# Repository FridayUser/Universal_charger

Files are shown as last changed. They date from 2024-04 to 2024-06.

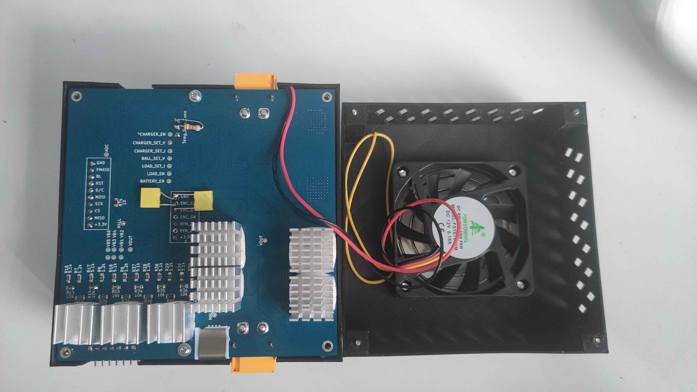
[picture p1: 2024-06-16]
Zdjęcia/IMG20240616181437.jpg

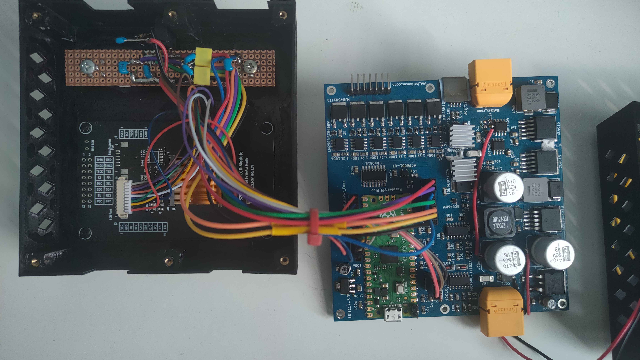
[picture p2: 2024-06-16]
Zdjęcia/IMG20240616181631.jpg

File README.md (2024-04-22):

View this project on [CADLAB.io](https://cadlab.io/project/28066). 

# Witam w projekcie ładowarki!

# Update plików
**Proszę o pisanie jasnego podsumowania i zwięzłych opisów** przy zatwierdzaniu plików. W szczególności plików innych niż programy. Pamietajcie, że po zatwierdzeniu należy też pliki przesłać. ewentualnie dodać jakieś nowe. Jeśli ktoś nie ogarnia gita to polecam wersję desktop.
## Tworzenie plików i folderów
Starajmy się twożyć jak najbardziej przejrzyście to repozytorium, żeby się poprostu nie zgubić w tym wszystkim

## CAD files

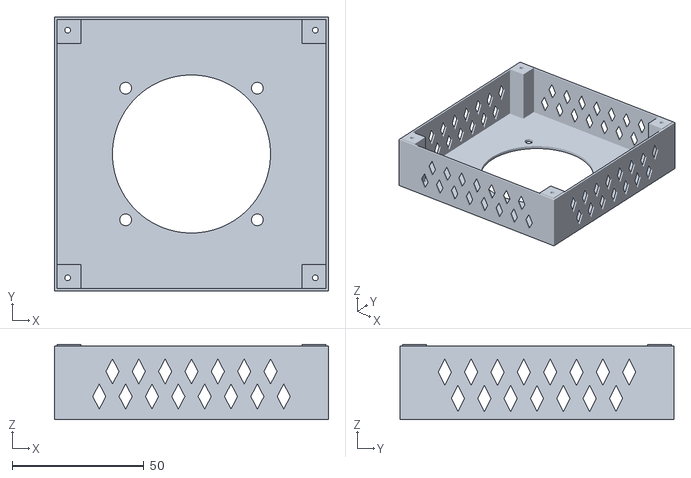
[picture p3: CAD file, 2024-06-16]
Obudowa/obudowa_d.stl
104.0 x 104.0 x 28.5

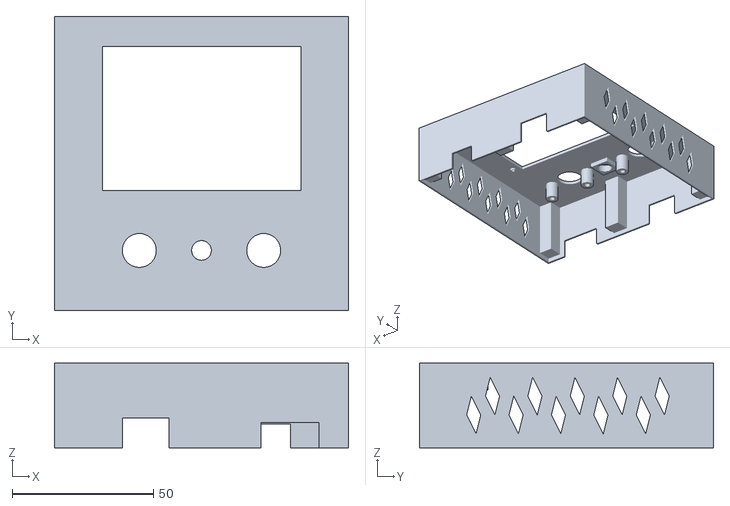
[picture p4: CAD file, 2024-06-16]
Obudowa/obudowa_t.stl
104.0 x 104.0 x 30.0

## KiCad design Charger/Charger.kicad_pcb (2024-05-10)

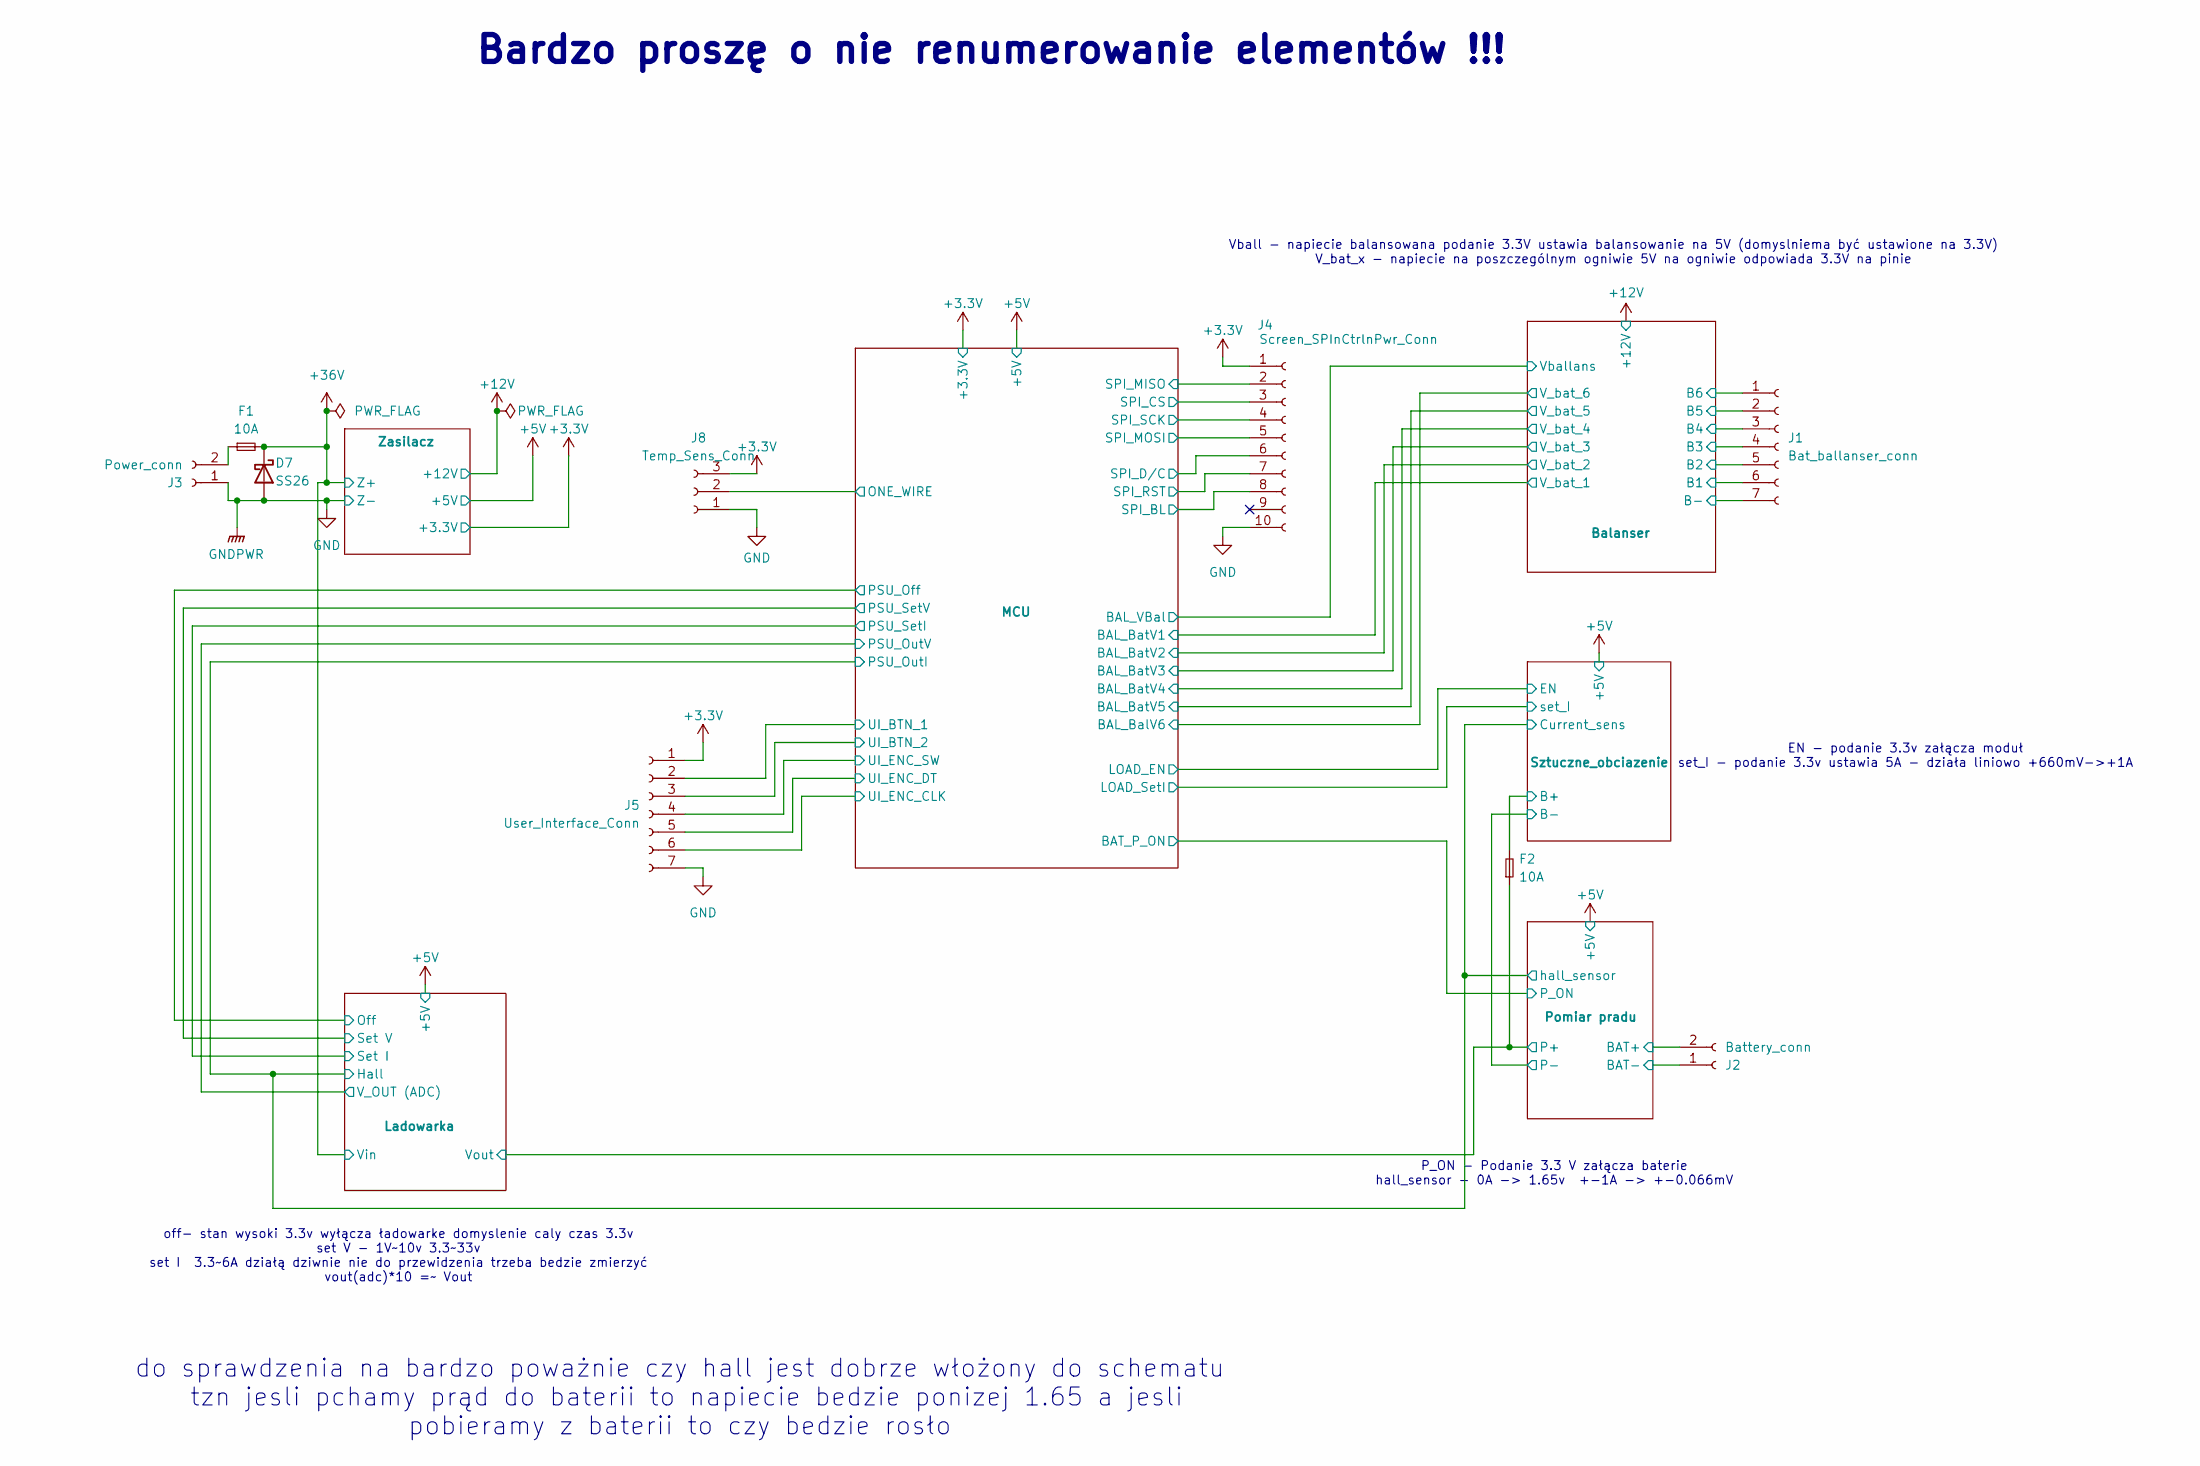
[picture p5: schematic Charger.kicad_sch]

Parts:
D7: SS26; D_SMA
F1, F2: 10A; Fuse_2010_5025Metric_Pad1.52x2.65mm_HandSolder
J1: Bat_ballanser_conn; PinHeader_1x07_P2.54mm_Horizontal
J2: Battery_conn; AMASS_XT60PW-M_1x02_P7.20mm_Horizontal
J3: Power_conn; AMASS_XT60PW-M_1x02_P7.20mm_Horizontal
J4: Screen_SPInCtrlnPwr_Conn; PinHeader_1x10_P2.54mm_Vertical
J5: User_Interface_Conn; PinHeader_1x07_P2.54mm_Vertical
J8: Temp_Sens_Conn; PinHeader_1x03_P2.54mm_Vertical

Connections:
+3.3V: J4.1, J5.1, J8.3; also elsewhere on the board
+36V: D7.1 (K), F1.2; also elsewhere on the board
/Balanser/B1: J1.6; also elsewhere on the board
/Balanser/B2: J1.5; also elsewhere on the board
/Balanser/B3: J1.4; also elsewhere on the board
/Balanser/B4: J1.3; also elsewhere on the board
/Balanser/B5: J1.2; also elsewhere on the board
/Balanser/B6: J1.1; also elsewhere on the board
/Ladowarka/Vout: F2.1; also elsewhere on the board
/Pomiar pradu/BAT+: J2.2; also elsewhere on the board
/Pomiar pradu/BAT-: J2.1; also elsewhere on the board
/Sztuczne_obciazenie/B+: F2.2; also elsewhere on the board
GND: D7.2 (A), J1.7, J3.1, J4.10, J5.7, J8.1; also elsewhere on the board
GPIO4: J8.2; also elsewhere on the board
GPIO11: J5.6; also elsewhere on the board
GPIO12: J5.5; also elsewhere on the board
GPIO13: J5.4; also elsewhere on the board
GPIO14: J5.3; also elsewhere on the board
GPIO15: J5.2; also elsewhere on the board
GPIO16: J4.2; also elsewhere on the board
GPIO17: J4.3; also elsewhere on the board
GPIO18: J4.4; also elsewhere on the board
GPIO19: J4.5; also elsewhere on the board
GPIO20: J4.6; also elsewhere on the board
GPIO21: J4.7; also elsewhere on the board
GPIO22: J4.8; also elsewhere on the board
unnamed: F1.1, J3.2

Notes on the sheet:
EN - podanie 3.3v załącza moduł set_I - podanie 3.3v ustawia 5A - działa liniowo +660mV->+1A
off- stan wysoki 3.3v wyłącza ładowarke domyslenie caly czas 3.3v set V - 1V~10v 3.3~33v set I 3.3~6A działą dziwnie nie do przewidzenia trzeba bedzie zmierzyć vout(adc)*10 =~ Vout
Bardzo proszę o nie renumerowanie elementów !!!
Vball - napiecie balansowana podanie 3.3V ustawia balansowanie na 5V (domyslniema być ustawione na 3.3V) V_bat_x - napiecie na poszczególnym ogniwie 5V na ogniwie odpowiada 3.3V na pinie
do sprawdzenia na bardzo poważnie czy hall jest dobrze włożony do schematu tzn jesli pchamy prąd do baterii to napiecie bedzie ponizej 1.65 a jesli pobieramy z baterii to czy bedzie rosło
P_ON - Podanie 3.3 V załącza baterie hall_sensor - 0A -> 1.65v +-1A -> +-0.066mV

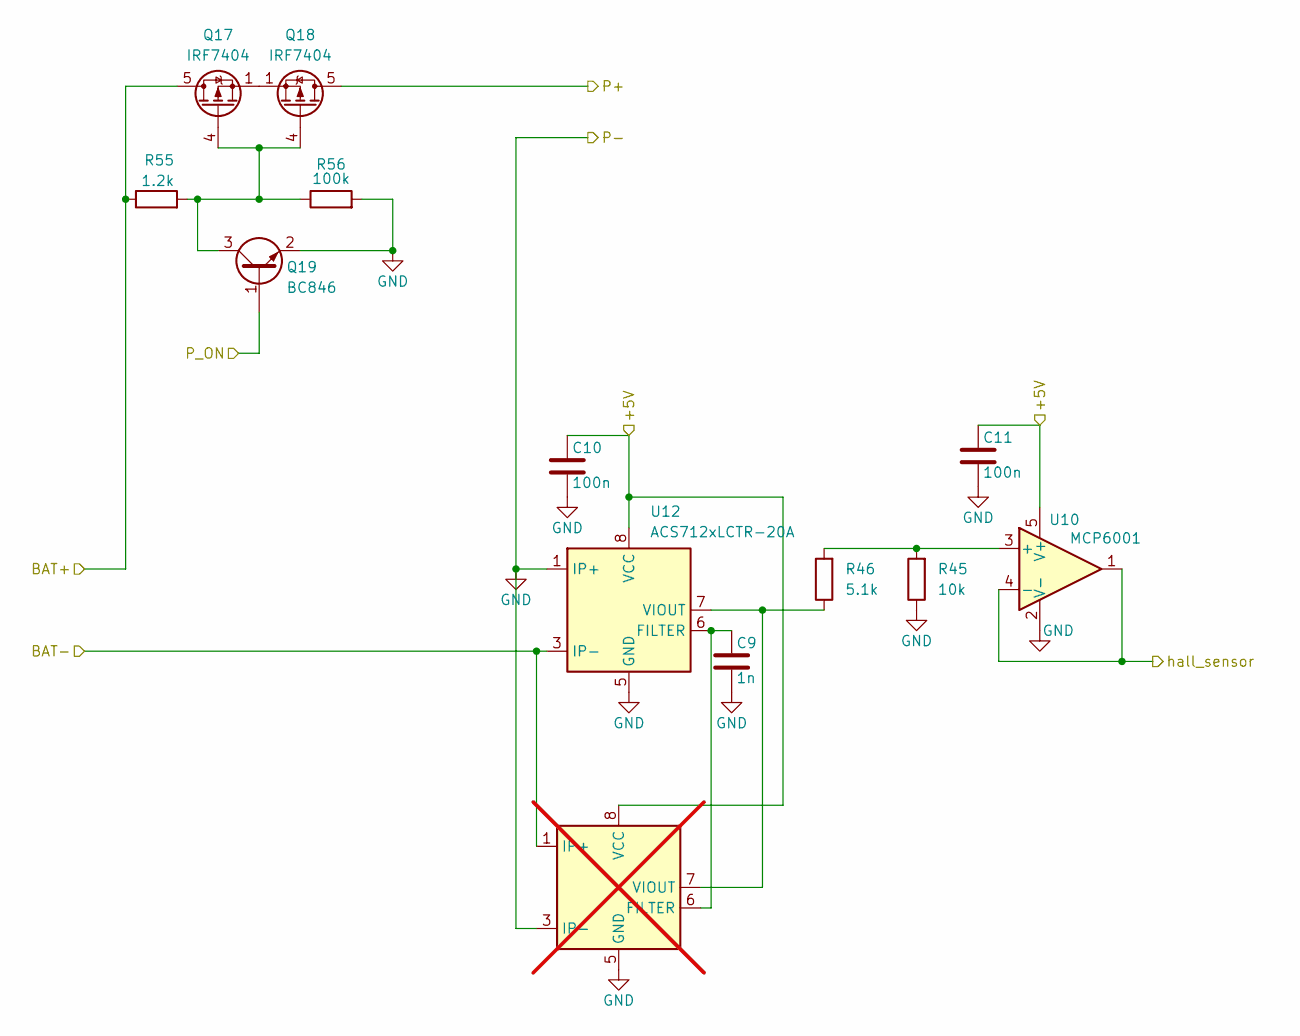
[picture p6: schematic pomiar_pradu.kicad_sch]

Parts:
C9: 1n; C_0805_2012Metric_Pad1.18x1.45mm_HandSolder
C10, C11: 100n; C_0805_2012Metric_Pad1.18x1.45mm_HandSolder
Q17, Q18: IRF7404; SOIC-8_3.9x4.9mm_P1.27mm
Q19: BC846; SOT-323_SC-70
R45: 10k; R_0805_2012Metric_Pad1.20x1.40mm_HandSolder
R46: 5.1k; R_0805_2012Metric_Pad1.20x1.40mm_HandSolder
R55: 1.2k; R_0805_2012Metric_Pad1.20x1.40mm_HandSolder
R56: 100k; R_0805_2012Metric_Pad1.20x1.40mm_HandSolder
U7: ACS712xLCTR-20A; SOIC-8_3.9x4.9mm_P1.27mm; not fitted
U10: MCP6001; SOT-23-5
U12: ACS712xLCTR-20A; SOIC-8_3.9x4.9mm_P1.27mm

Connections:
+5V: C10.1, C11.1, U7.8 (VCC), U10.5 (V+), U12.8 (VCC); also elsewhere on the board
/Ladowarka/Hall: U10.1, U10.4 (-); also elsewhere on the board
/Ladowarka/Vout: Q18.5 (D), Q18.6 (D), Q18.7 (D), Q18.8 (D); also elsewhere on the board
/Pomiar pradu/BAT+: Q17.5 (D), Q17.6 (D), Q17.7 (D), Q17.8 (D), R55.1; also elsewhere on the board
/Pomiar pradu/BAT-: U7.1 (IP+), U7.2 (IP+), U12.3 (IP-), U12.4 (IP-); also elsewhere on the board
GND: C9.2, C10.2, C11.2, Q19.2 (E), R45.1, R56.2, U7.3 (IP-), U7.4 (IP-), U7.5 (GND), U10.2 (V-), U12.1 (IP+), U12.2 (IP+), U12.5 (GND); also elsewhere on the board
GPIO10: Q19.1 (B); also elsewhere on the board
unnamed: Q17.4 (G), Q18.4 (G), Q19.3 (C), R55.2, R56.1
unnamed: Q17.1 (S), Q17.2 (S), Q17.3 (S), Q18.1 (S), Q18.2 (S), Q18.3 (S)
unnamed: R45.2, R46.2, U10.3 (+)
unnamed: C9.1, U7.6 (FILTER), U12.6 (FILTER)
unnamed 106: R46.1, U7.7 (VIOUT), U12.7 (VIOUT); also elsewhere on the board

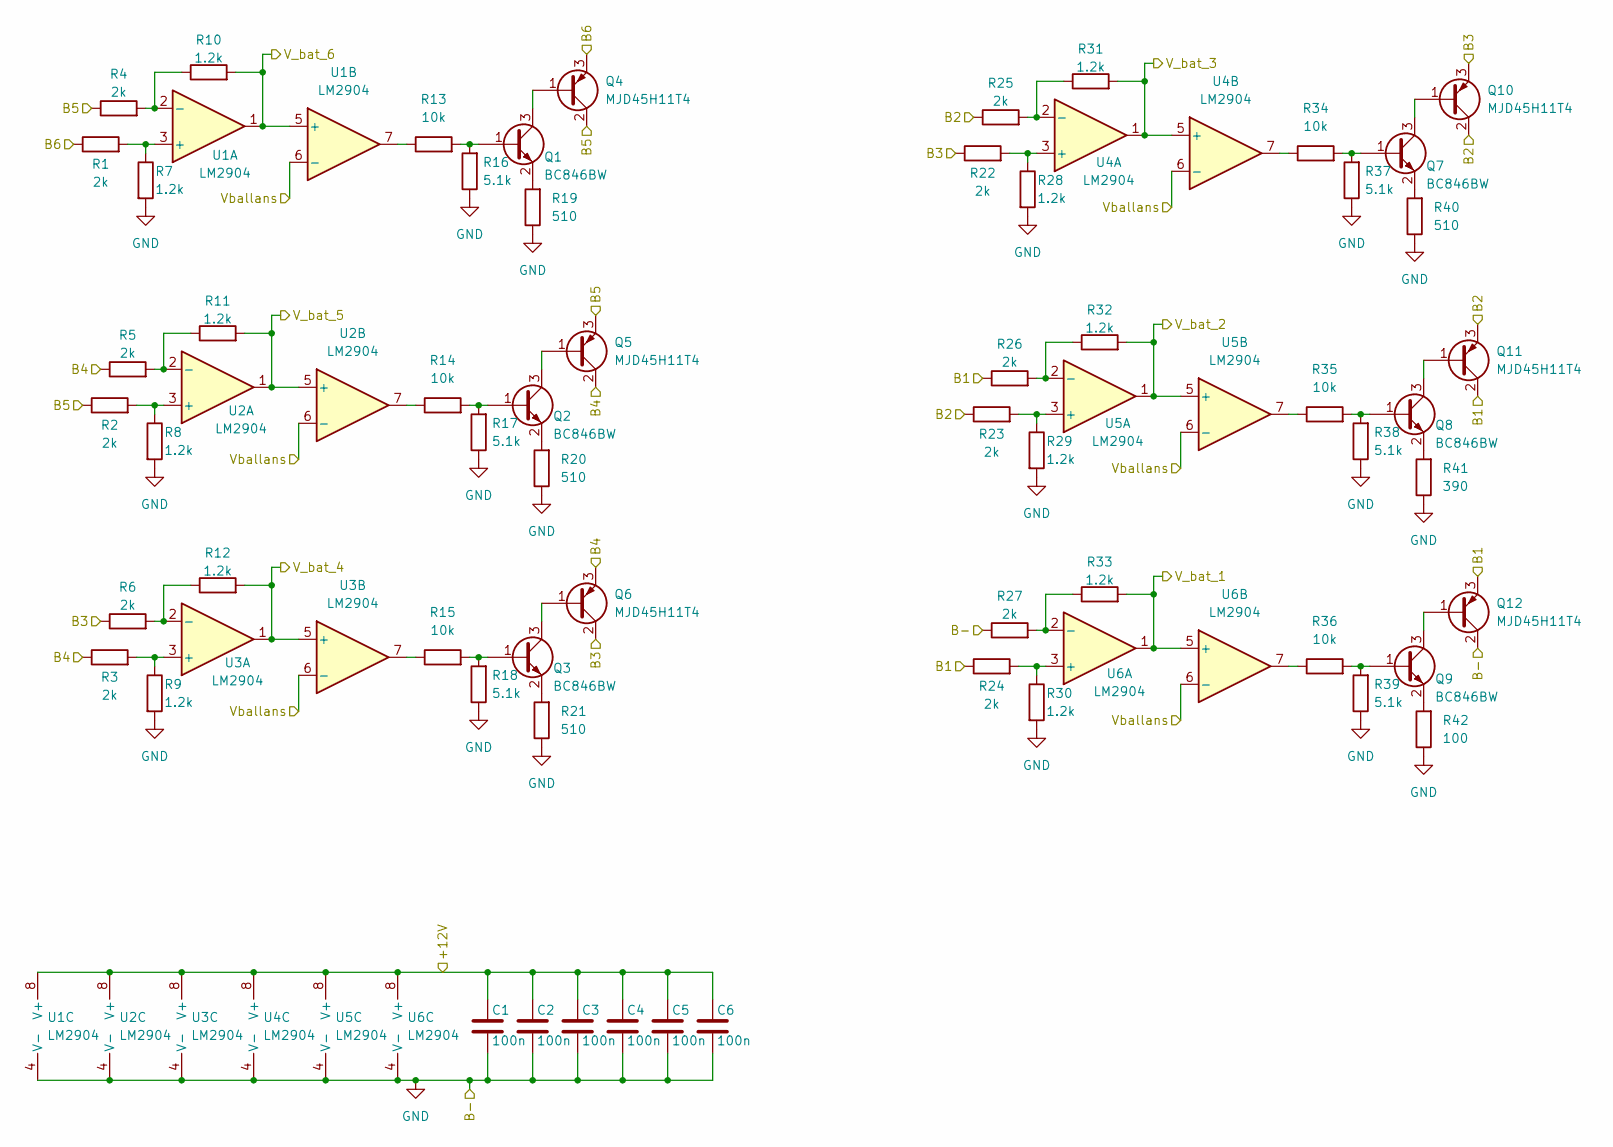
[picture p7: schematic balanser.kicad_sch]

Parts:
C1, C2, C3, C4, C5, C6: 100n; C_0805_2012Metric_Pad1.18x1.45mm_HandSolder
Q1, Q2, Q3, Q7, Q8, Q9: BC846BW; SOT-323_SC-70
Q4, Q5, Q6, Q10, Q11, Q12: MJD45H11T4; TO-252-2
R1, R2, R3, R4, R5, R6, R22, R23, R24, R25, R26, R27: 2k; R_0805_2012Metric_Pad1.20x1.40mm_HandSolder
R7, R8, R9, R10, R11, R12, R28, R29, R30, R31, R32, R33: 1.2k; R_0805_2012Metric_Pad1.20x1.40mm_HandSolder
R13, R14, R15, R34, R35, R36: 10k; R_0805_2012Metric_Pad1.20x1.40mm_HandSolder
R16, R17, R18, R37, R38, R39: 5.1k; R_0805_2012Metric_Pad1.20x1.40mm_HandSolder
R19, R20, R21, R40: 510; R_0805_2012Metric_Pad1.20x1.40mm_HandSolder
R41: 390; R_0805_2012Metric_Pad1.20x1.40mm_HandSolder
R42: 100; R_0805_2012Metric_Pad1.20x1.40mm_HandSolder
U1, U2, U3, U4, U5, U6: LM2904; SO-8_3.9x4.9mm_P1.27mm

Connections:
+12V: C1.1, C2.1, C3.1, C4.1, C5.1, C6.1, U1.8 (V+), U2.8 (V+), U3.8 (V+), U4.8 (V+), U5.8 (V+), U6.8 (V+); also elsewhere on the board
/Balanser/B1: Q11.2 (C), Q12.3 (E), R24.1, R26.1; also elsewhere on the board
/Balanser/B2: Q10.2 (C), Q11.3 (E), R23.1, R25.1; also elsewhere on the board
/Balanser/B3: Q6.2 (C), Q10.3 (E), R6.1, R22.1; also elsewhere on the board
/Balanser/B4: Q5.2 (C), Q6.3 (E), R3.1, R5.1; also elsewhere on the board
/Balanser/B5: Q4.2 (C), Q5.3 (E), R2.1, R4.1; also elsewhere on the board
/Balanser/B6: Q4.3 (E), R1.1; also elsewhere on the board
/Balanser/V_bat_1: R33.2, U6.1, U6.5 (+); also elsewhere on the board
/Balanser/V_bat_2: R32.2, U5.1, U5.5 (+); also elsewhere on the board
/Balanser/V_bat_3: R31.2, U4.1, U4.5 (+); also elsewhere on the board
/Balanser/V_bat_4: R12.2, U3.1, U3.5 (+); also elsewhere on the board
/Balanser/V_bat_5: R11.2, U2.1, U2.5 (+); also elsewhere on the board
/Balanser/V_bat_6: R10.2, U1.1, U1.5 (+); also elsewhere on the board
/Balanser/Vballans: U1.6 (-), U2.6 (-), U3.6 (-), U4.6 (-), U5.6 (-), U6.6 (-); also elsewhere on the board
GND: C1.2, C2.2, C3.2, C4.2, C5.2, C6.2, Q12.2 (C), R7.2, R8.2, R9.2, R16.1, R17.1, R18.1, R19.1, R20.1, R21.1, R27.1, R28.2, R29.2, R30.2, R37.1, R38.1, R39.1, R40.1, R41.1, R42.1, U1.4 (V-), U2.4 (V-), U3.4 (V-), U4.4 (V-), U5.4 (V-), U6.4 (V-); also elsewhere on the board
unnamed: Q1.1 (B), R13.2, R16.2
unnamed: Q1.3 (C), Q4.1 (B)
unnamed: Q1.2 (E), R19.2
unnamed: Q2.1 (B), R14.2, R17.2
unnamed: Q2.3 (C), Q5.1 (B)
unnamed: Q2.2 (E), R20.2
unnamed: Q3.1 (B), R15.2, R18.2
unnamed: Q3.3 (C), Q6.1 (B)
unnamed: Q3.2 (E), R21.2
unnamed: Q7.1 (B), R34.2, R37.2
unnamed: Q7.2 (E), R40.2
unnamed: Q8.1 (B), R35.2, R38.2
unnamed: Q8.2 (E), R41.2
unnamed: Q9.1 (B), R36.2, R39.2
unnamed: Q9.2 (E), R42.2
unnamed: Q7.3 (C), Q10.1 (B)
unnamed: Q8.3 (C), Q11.1 (B)
unnamed: Q9.3 (C), Q12.1 (B)
unnamed: R13.1, U1.7
unnamed: R14.1, U2.7
unnamed: R15.1, U3.7
unnamed: R34.1, U4.7
unnamed: R35.1, U5.7
unnamed: R36.1, U6.7
unnamed: R1.2, R7.1, U1.3 (+)
unnamed: R4.2, R10.1, U1.2 (-)
unnamed: R2.2, R8.1, U2.3 (+)
unnamed: R5.2, R11.1, U2.2 (-)
unnamed: R3.2, R9.1, U3.3 (+)
unnamed: R6.2, R12.1, U3.2 (-)
unnamed: R22.2, R28.1, U4.3 (+)
unnamed: R25.2, R31.1, U4.2 (-)
unnamed: R23.2, R29.1, U5.3 (+)
unnamed: R26.2, R32.1, U5.2 (-)
unnamed: R24.2, R30.1, U6.3 (+)
unnamed: R27.2, R33.1, U6.2 (-)

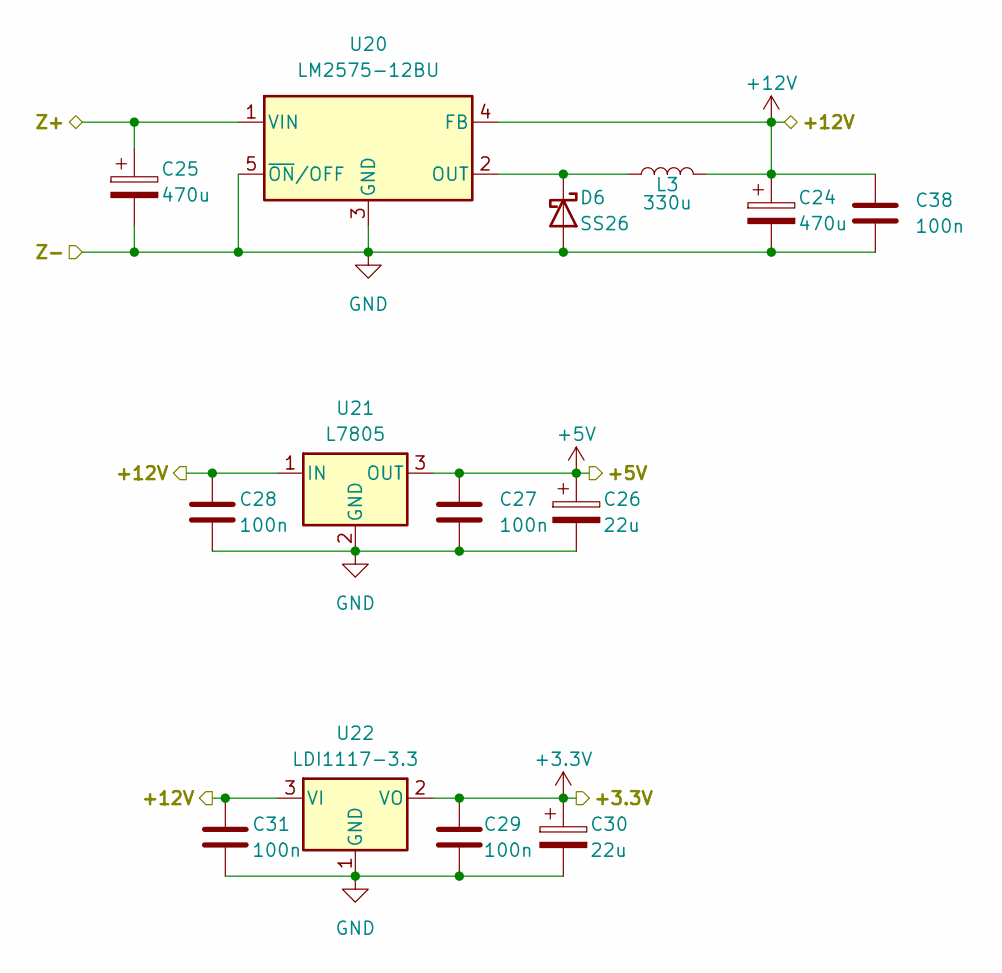
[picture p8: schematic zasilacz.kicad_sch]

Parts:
C24, C25: 470u; CP_Elec_12.5x13.5
C26, C30: 22u; CP_Elec_4x5.4
C27, C28, C29, C31, C38: 100n; C_0805_2012Metric_Pad1.18x1.45mm_HandSolder
D6: SS26; D_SMA
L3: 330u; L_Bourns_SRR1208_12.7x12.7mm
U20: LM2575-12BU; TO-263-5_TabPin3
U21: L7805; TO-263-2
U22: LDI1117-3.3; SOT-223-3_TabPin2

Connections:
+3.3V: C29.1, C30.1, U22.2 (VO); also elsewhere on the board
+5V: C26.1, C27.1, U21.3 (OUT); also elsewhere on the board
+12V: C24.1, C28.1, C31.1, C38.1, L3.2, U20.4 (FB), U21.1 (IN), U22.3 (VI); also elsewhere on the board
+36V: C25.1, U20.1 (VIN); also elsewhere on the board
GND: C24.2, C25.2, C26.2, C27.2, C28.2, C29.2, C30.2, C31.2, C38.2, D6.2 (A), U20.3 (GND), U20.5 (~ON/OFF), U21.2 (GND), U22.1 (GND); also elsewhere on the board
unnamed: D6.1 (K), L3.1, U20.2 (OUT)

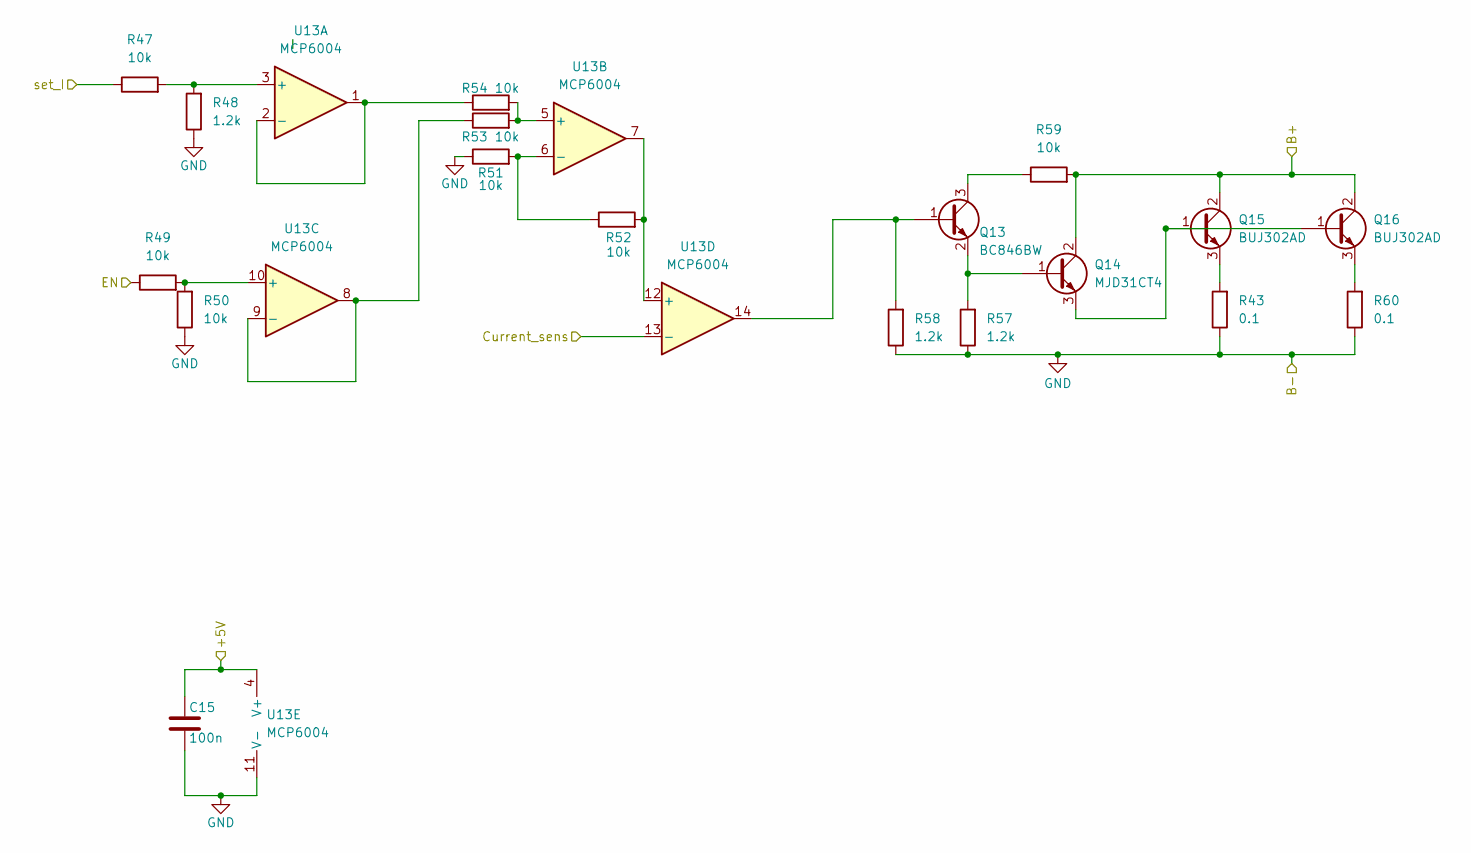
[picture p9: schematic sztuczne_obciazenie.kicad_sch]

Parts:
C15: 100n; C_0805_2012Metric_Pad1.18x1.45mm_HandSolder
Q13: BC846BW; SOT-323_SC-70
Q14: MJD31CT4; TO-252-2
Q15, Q16: BUJ302AD; TO-252-2
R43, R60: 0.1; R_1206_3216Metric_Pad1.30x1.75mm_HandSolder
R47, R49, R50, R51, R52, R53, R54, R59: 10k; R_0805_2012Metric_Pad1.20x1.40mm_HandSolder
R48, R57, R58: 1.2k; R_0805_2012Metric_Pad1.20x1.40mm_HandSolder
U13: MCP6004; SOIC-14_3.9x8.7mm_P1.27mm

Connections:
+5V: C15.1, U13.4 (V+); also elsewhere on the board
/Ladowarka/Hall: U13.13 (-); also elsewhere on the board
/MCU/LOAD_SetI: R47.1; also elsewhere on the board
/Sztuczne_obciazenie/B+: Q14.2 (C), Q15.2 (C), Q16.2 (C), R59.2; also elsewhere on the board
GND: C15.2, R43.1, R48.1, R50.1, R51.1, R57.1, R58.1, R60.1, U13.11 (V-); also elsewhere on the board
GPIO8: R49.1; also elsewhere on the board
unnamed: Q13.1 (B), R58.2, U13.14
unnamed: Q13.3 (C), R59.1
unnamed: Q13.2 (E), Q14.1 (B), R57.2
unnamed: Q14.3 (E), Q15.1 (B), Q16.1 (B)
unnamed: Q15.3 (E), R43.2
unnamed: Q16.3 (E), R60.2
unnamed: R47.2, R48.2, U13.3 (+)
unnamed: R54.1, U13.1, U13.2 (-)
unnamed: R53.2, R54.2, U13.5 (+)
unnamed: R51.2, R52.1, U13.6 (-)
unnamed: R49.2, R50.2, U13.10 (+)
unnamed: R53.1, U13.8, U13.9 (-)
unnamed: R52.2, U13.7, U13.12 (+)

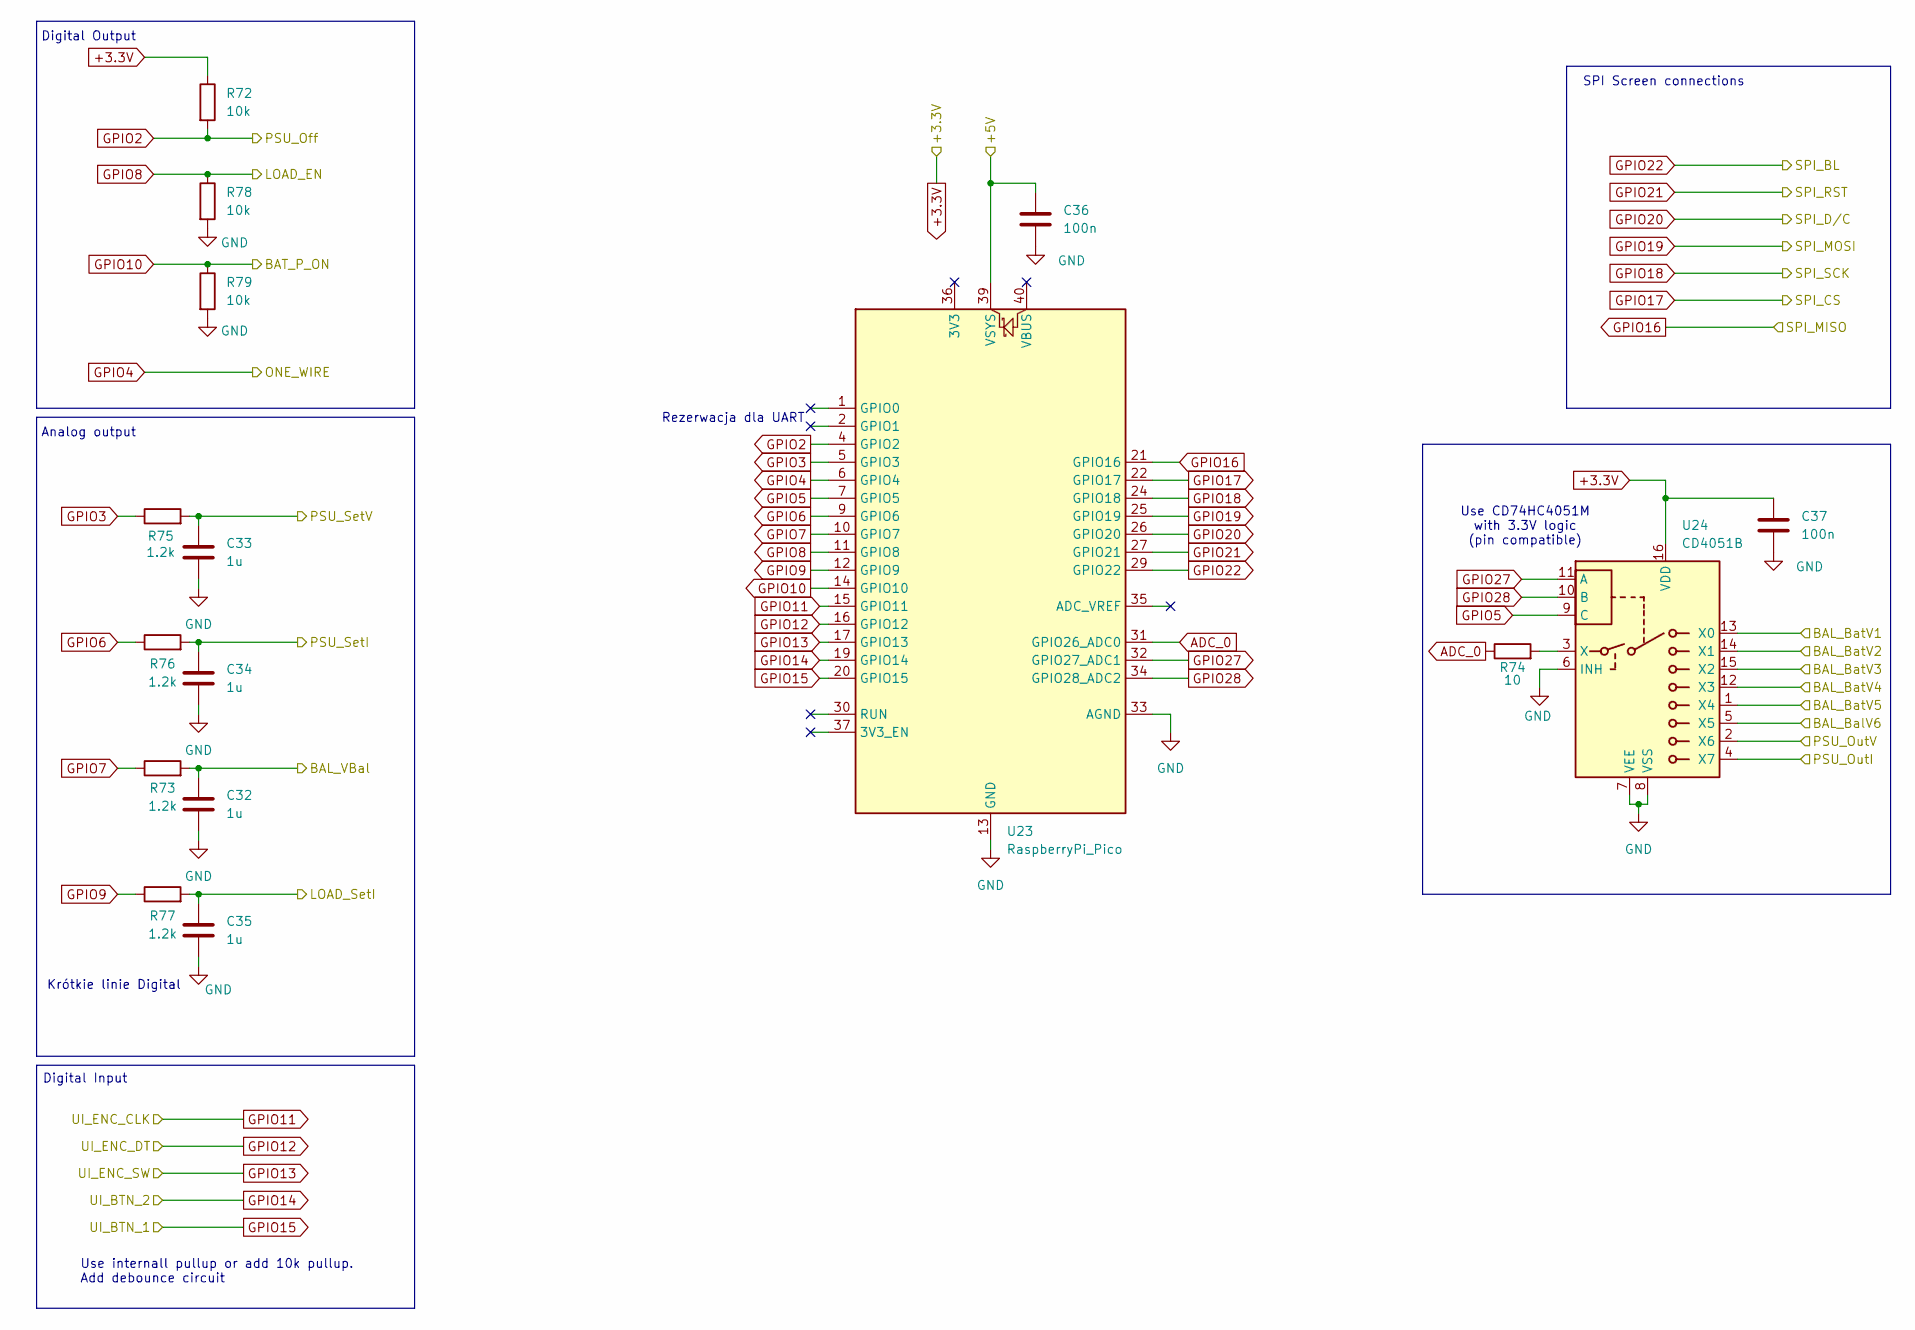
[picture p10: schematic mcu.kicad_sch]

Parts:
C32, C33, C34, C35: 1u; C_0805_2012Metric_Pad1.18x1.45mm_HandSolder
C36, C37: 100n; C_0805_2012Metric_Pad1.18x1.45mm_HandSolder
R72, R78, R79: 10k; R_0805_2012Metric_Pad1.20x1.40mm_HandSolder
R73, R75, R76, R77: 1.2k; R_0805_2012Metric_Pad1.20x1.40mm_HandSolder
R74: 10; R_0805_2012Metric_Pad1.20x1.40mm_HandSolder
U23: RaspberryPi_Pico; RaspberryPi_Pico_Common_SMD
U24: CD4051B; SO-16_5.3x10.2mm_P1.27mm

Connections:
+3.3V: C37.1, R72.1, U24.16 (VDD); also elsewhere on the board
+5V: C36.1, U23.39 (VSYS); also elsewhere on the board
/Balanser/V_bat_1: U24.13 (X0); also elsewhere on the board
/Balanser/V_bat_2: U24.14 (X1); also elsewhere on the board
/Balanser/V_bat_3: U24.15 (X2); also elsewhere on the board
/Balanser/V_bat_4: U24.12 (X3); also elsewhere on the board
/Balanser/V_bat_5: U24.1 (X4); also elsewhere on the board
/Balanser/V_bat_6: U24.5 (X5); also elsewhere on the board
/Balanser/Vballans: C32.1, R73.2; also elsewhere on the board
/Ladowarka/Hall: U24.4 (X7); also elsewhere on the board
/Ladowarka/Set I: C34.1, R76.2; also elsewhere on the board
/Ladowarka/Set V: C33.1, R75.2; also elsewhere on the board
/Ladowarka/V_OUT (ADC): U24.2 (X6); also elsewhere on the board
/MCU/LOAD_SetI: C35.1, R77.2; also elsewhere on the board
ADC_0: R74.1, U23.31 (GPIO26_ADC0); also elsewhere on the board
GND: C32.2, C33.2, C34.2, C35.2, C36.2, C37.2, R78.2, R79.2, U23.3 (GND), U23.8 (GND), U23.13 (GND), U23.18 (GND), U23.23 (GND), U23.28 (GND), U23.33 (AGND), U23.38 (GND), U24.6 (INH), U24.7 (VEE), U24.8 (VSS); also elsewhere on the board
GPIO2: R72.2, U23.4 (GPIO2); also elsewhere on the board
GPIO3: R75.1, U23.5 (GPIO3)
GPIO4: U23.6 (GPIO4); also elsewhere on the board
GPIO5: U23.7 (GPIO5), U24.9 (C)
GPIO6: R76.1, U23.9 (GPIO6)
GPIO7: R73.1, U23.10 (GPIO7)
GPIO8: R78.1, U23.11 (GPIO8); also elsewhere on the board
GPIO9: R77.1, U23.12 (GPIO9)
GPIO10: R79.1, U23.14 (GPIO10); also elsewhere on the board
GPIO11: U23.15 (GPIO11); also elsewhere on the board
GPIO12: U23.16 (GPIO12); also elsewhere on the board
GPIO13: U23.17 (GPIO13); also elsewhere on the board
GPIO14: U23.19 (GPIO14); also elsewhere on the board
GPIO15: U23.20 (GPIO15); also elsewhere on the board
GPIO16: U23.21 (GPIO16); also elsewhere on the board
GPIO17: U23.22 (GPIO17); also elsewhere on the board
GPIO18: U23.24 (GPIO18); also elsewhere on the board
GPIO19: U23.25 (GPIO19); also elsewhere on the board
GPIO20: U23.26 (GPIO20); also elsewhere on the board
GPIO21: U23.27 (GPIO21); also elsewhere on the board
GPIO22: U23.29 (GPIO22); also elsewhere on the board
GPIO27: U23.32 (GPIO27_ADC1), U24.11 (A)
GPIO28: U23.34 (GPIO28_ADC2), U24.10 (B)
unnamed: R74.2, U24.3 (X)

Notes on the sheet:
Rezerwacja dla UART
Analog output
Digital Output
SPI Screen connections
Krótkie linie Digital
Use CD74HC4051M with 3.3V logic (pin compatible)
Use internall pullup or add 10k pullup. Add debounce circuit
Digital Input

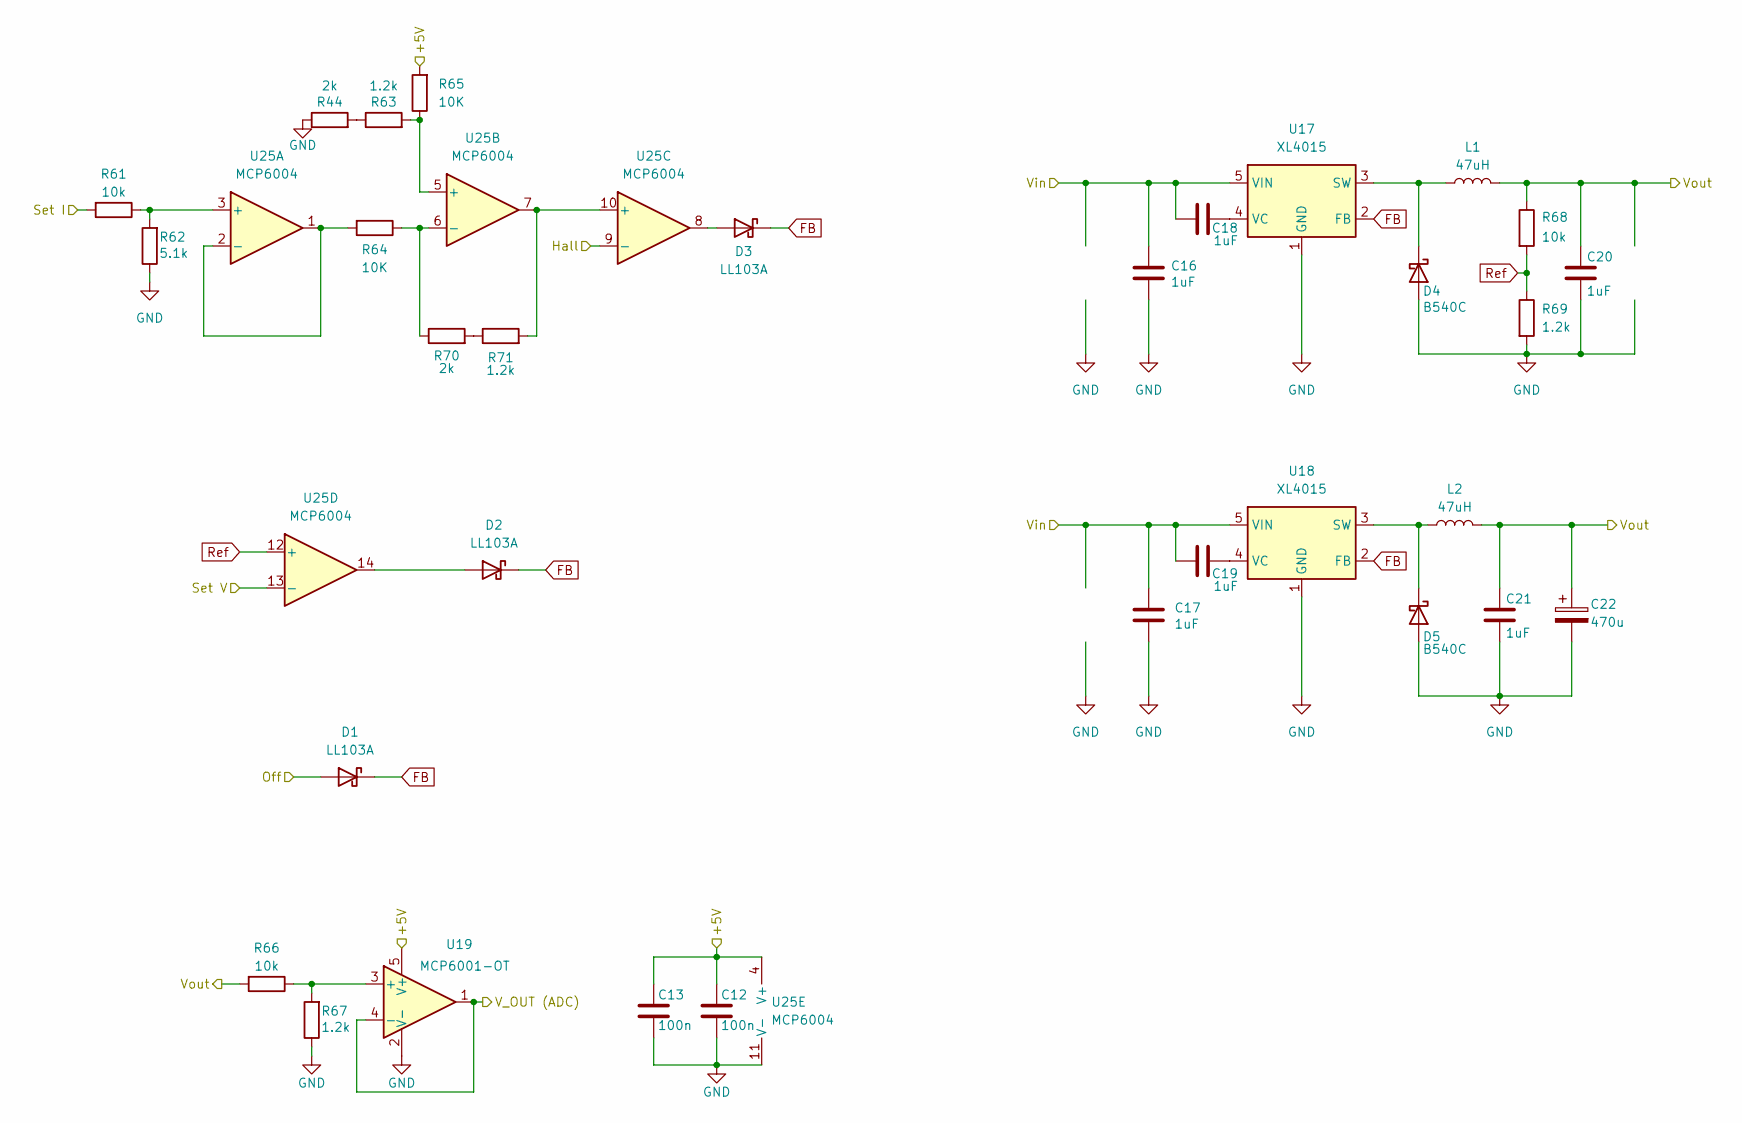
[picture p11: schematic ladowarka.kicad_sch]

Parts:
C12, C13: 100n; C_0805_2012Metric_Pad1.18x1.45mm_HandSolder
C16, C17, C18, C19, C20, C21: 1uF; C_0805_2012Metric_Pad1.18x1.45mm_HandSolder
C22: 470u; CP_Elec_12.5x13.5
D1, D2, D3: LL103A; D_MiniMELF
D4, D5: B540C; D_3220_8050Metric_Pad2.65x5.15mm_HandSolder
L1, L2: 47uH; L_Bourns_SRP1038C_10.0x10.0mm
R44, R70: 2k; R_0805_2012Metric_Pad1.20x1.40mm_HandSolder
R61, R66, R68: 10k; R_0805_2012Metric_Pad1.20x1.40mm_HandSolder
R62: 5.1k; R_0805_2012Metric_Pad1.20x1.40mm_HandSolder
R63, R67, R69, R71: 1.2k; R_0805_2012Metric_Pad1.20x1.40mm_HandSolder
R64, R65: 10K; R_0805_2012Metric_Pad1.20x1.40mm_HandSolder
U17, U18: XL4015; TO-263-5_TabPin3
U19: MCP6001-OT; SOT-23-5
U25: MCP6004; SOIC-14_3.9x8.7mm_P1.27mm

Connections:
+5V: C12.1, C13.1, R65.2, U19.5 (V+), U25.4 (V+); also elsewhere on the board
+36V: C16.1, C17.1, C18.1, C19.1, U17.5 (VIN), U18.5 (VIN); also elsewhere on the board
/Ladowarka/Hall: U25.9 (-); also elsewhere on the board
/Ladowarka/Set I: R61.2; also elsewhere on the board
/Ladowarka/Set V: U25.13 (-); also elsewhere on the board
/Ladowarka/V_OUT (ADC): U19.1, U19.4 (-); also elsewhere on the board
/Ladowarka/Vout: C20.1, C21.1, C22.1, L1.2, L2.2, R66.2, R68.1; also elsewhere on the board
FB: D1.1 (K), D2.1 (K), D3.1 (K), U17.2 (FB), U18.2 (FB)
GND: C12.2, C13.2, C16.2, C17.2, C20.2, C21.2, C22.2, D4.2 (A), D5.2 (A), R44.1, R62.1, R67.1, R69.2, U17.1 (GND), U18.1 (GND), U19.2 (V-), U25.11 (V-); also elsewhere on the board
GPIO2: D1.2 (A); also elsewhere on the board
unnamed: D2.2 (A), U25.14
unnamed: D3.2 (A), U25.8
unnamed: D4.1 (K), L1.1, U17.3 (SW)
unnamed: D5.1 (K), L2.1, U18.3 (SW)
unnamed: R44.2, R63.1
unnamed: R70.2, R71.1
unnamed: C18.2, U17.4 (VC)
unnamed: C19.2, U18.4 (VC)
unnamed: R66.1, R67.2, U19.3 (+)
unnamed: R61.1, R62.2, U25.3 (+)
unnamed: R64.2, U25.1, U25.2 (-)
unnamed: R63.2, R65.1, U25.5 (+)
unnamed: R64.1, R70.1, U25.6 (-)
unnamed: R71.2, U25.7, U25.10 (+)
Ref: R68.2, R69.1, U25.12 (+)

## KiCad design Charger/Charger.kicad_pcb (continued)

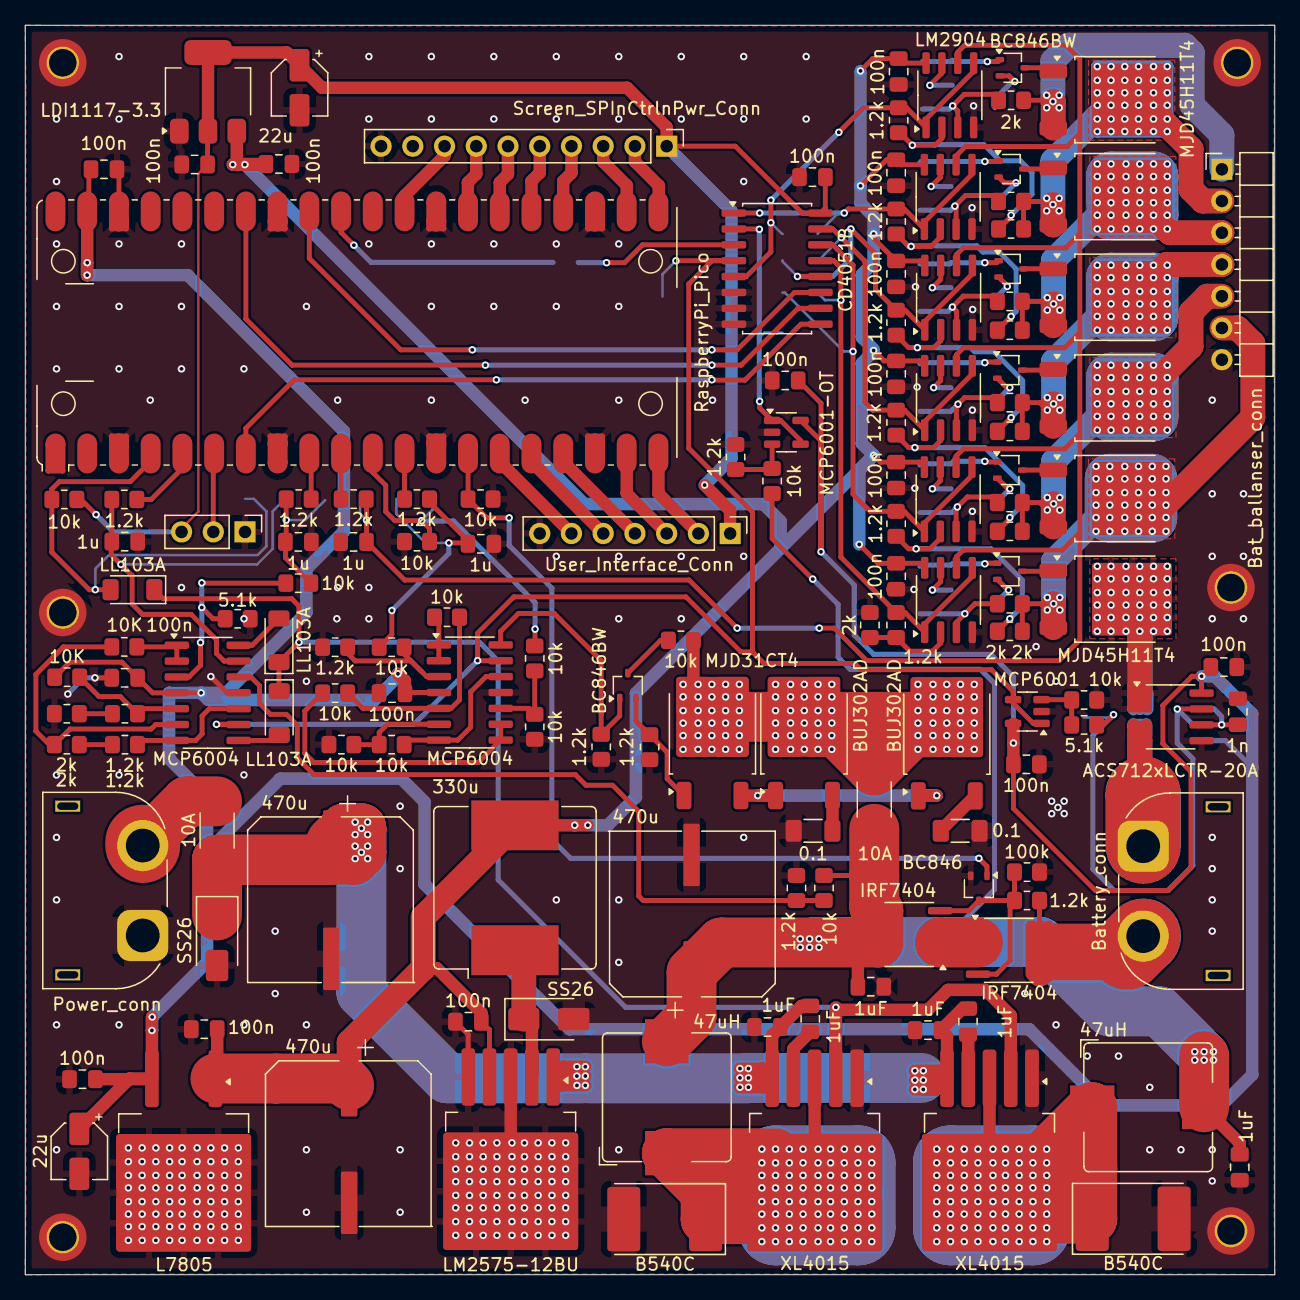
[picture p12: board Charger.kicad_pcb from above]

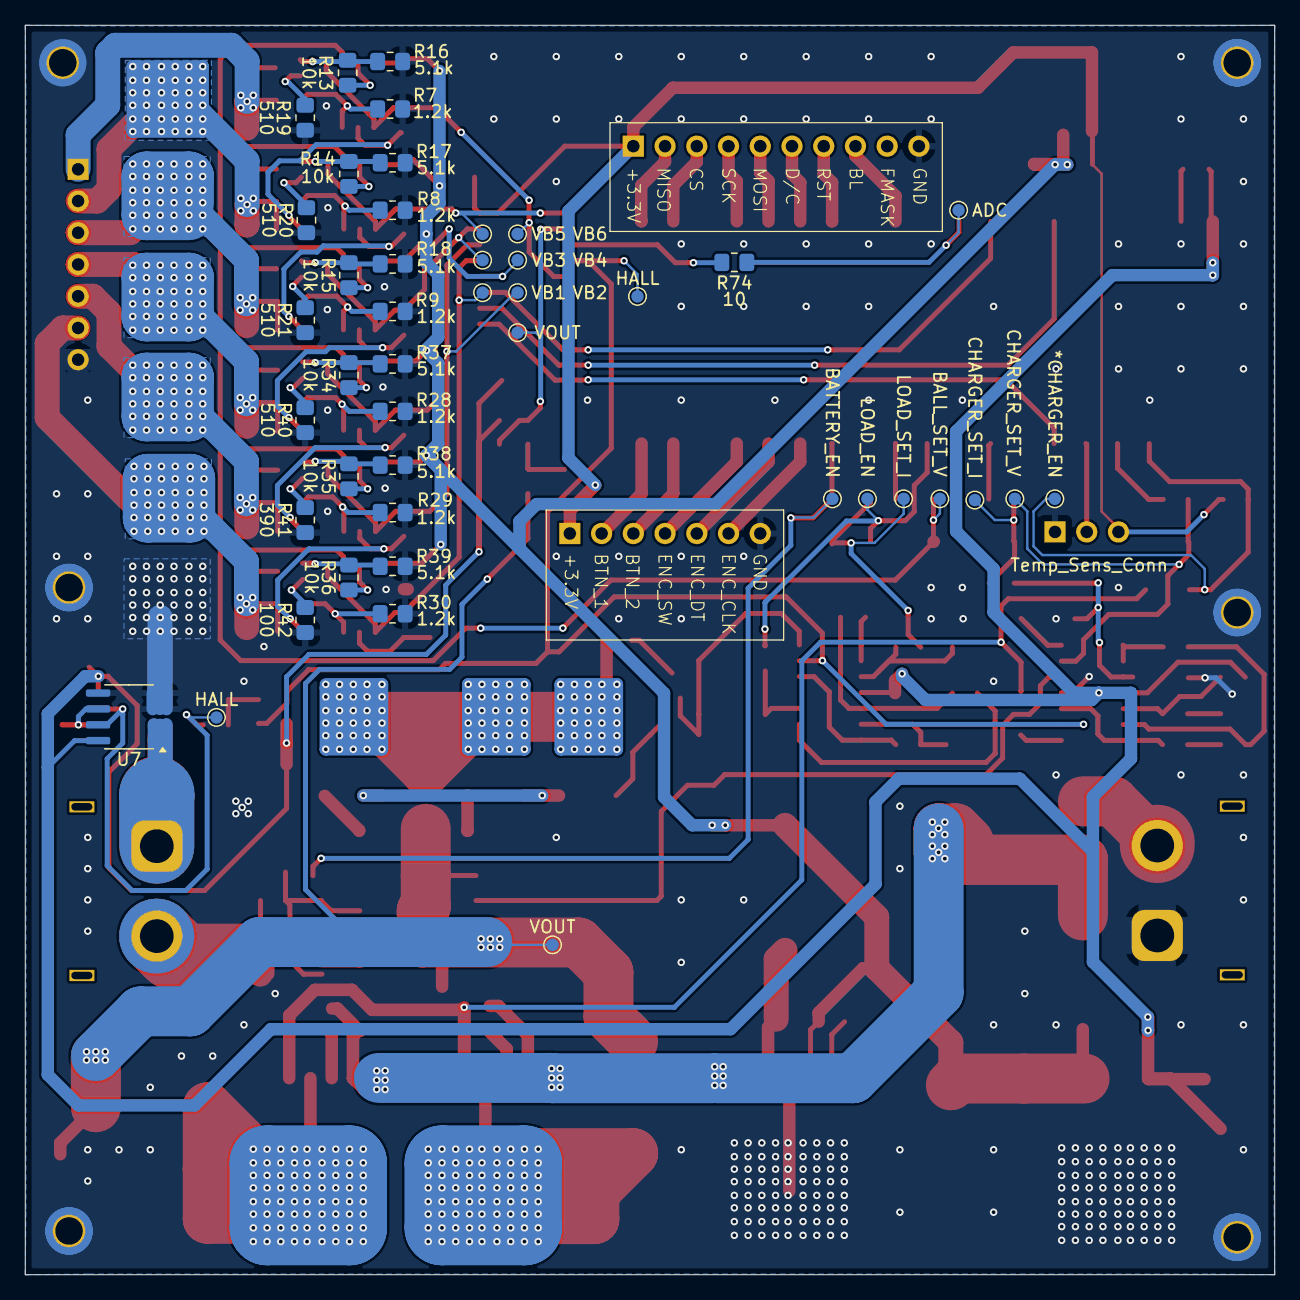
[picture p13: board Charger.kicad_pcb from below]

Board: 2 copper layers, 100.0 x 100.0 mm, 187 parts (44 on the bottom side), 124 nets.

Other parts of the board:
*CHARGER_EN: TestPoint_Pad_D1.0mm
ADC: TestPoint_Pad_D1.0mm
BALL_SET_V: TestPoint_Pad_D1.0mm
BATTERY_EN: TestPoint_Pad_D1.0mm
CHARGER_SET_I: TestPoint_Pad_D1.0mm
CHARGER_SET_V: TestPoint_Pad_D1.0mm
HALL: TestPoint_Pad_D1.0mm
HALL#2: TestPoint_Pad_D1.0mm
LOAD_EN: TestPoint_Pad_D1.0mm
LOAD_SET_I: TestPoint_Pad_D1.0mm
VB1, VB2, VB3, VB4, VB5, VB6: TestPoint_Pad_D1.0mm
VOUT: TestPoint_Pad_D1.0mm
VOUT#2: TestPoint_Pad_D1.0mm

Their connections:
/Balanser/V_bat_1: VB1.1; also elsewhere on the board
/Balanser/V_bat_2: VB2.1; also elsewhere on the board
/Balanser/V_bat_3: VB3.1; also elsewhere on the board
/Balanser/V_bat_4: VB4.1; also elsewhere on the board
/Balanser/V_bat_5: VB5.1; also elsewhere on the board
/Balanser/V_bat_6: VB6.1; also elsewhere on the board
/Balanser/Vballans: BALL_SET_V.1; also elsewhere on the board
/Ladowarka/Hall: HALL.1; also elsewhere on the board
/Ladowarka/Set I: CHARGER_SET_I.1; also elsewhere on the board
/Ladowarka/Set V: CHARGER_SET_V.1; also elsewhere on the board
/Ladowarka/V_OUT (ADC): VOUT.1; also elsewhere on the board
/Ladowarka/Vout: VOUT#2.1; also elsewhere on the board
/MCU/LOAD_SetI: LOAD_SET_I.1; also elsewhere on the board
ADC_0: ADC.1; also elsewhere on the board
GPIO2: *CHARGER_EN.1; also elsewhere on the board
GPIO8: LOAD_EN.1; also elsewhere on the board
GPIO10: BATTERY_EN.1; also elsewhere on the board
unnamed 106: HALL#2.1; also elsewhere on the board

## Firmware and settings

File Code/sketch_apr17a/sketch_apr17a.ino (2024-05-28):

#include <Arduino_GFX_Library.h>

#define GFX_BL 28 // Dostosuj zgodnie ze swoim pinem podświetlenia

#define BACKGROUND BLACK
#define TEXT_COLOR WHITE
#define HIGHLIGHT_COLOR BLUE

// Enkoder
#define ENCODER_PIN_A 2
#define ENCODER_PIN_B 3
#define ENCODER_BUTTON_PIN 4

volatile int encoderPos = 0;
int lastEncoderPosition = -1;
int menuIndex = 0;

const char* menuOptions[] = {"Opcja1", "Opcja2", "Opcja3", "Opcja4"};
const int menuLength = sizeof(menuOptions) / sizeof(menuOptions[0]);

Arduino_DataBus *bus = create_default_Arduino_DataBus();
Arduino_GFX *gfx = new Arduino_ST7789(bus, GFX_BL, 0 /* rotation */, false /* IPS */);

void IRAM_ATTR updateEncoder() {
  bool data = digitalRead(ENCODER_PIN_B);
  bool clk = digitalRead(ENCODER_PIN_A);
  if (data == clk) {
    encoderPos++;
  } else {
    encoderPos--;
  }
}

void setup() {
  Serial.begin(115200);
  
  if (!gfx->begin()) {
    Serial.println("gfx->begin() failed!");
    while (1);
  }
  gfx->fillScreen(BACKGROUND);
  gfx->setTextColor(TEXT_COLOR);

  pinMode(ENCODER_PIN_A, INPUT_PULLUP);
  pinMode(ENCODER_PIN_B, INPUT_PULLUP);
  pinMode(ENCODER_BUTTON_PIN, INPUT_PULLUP);

  attachInterrupt(digitalPinToInterrupt(ENCODER_PIN_A), updateEncoder, CHANGE);
  attachInterrupt(digitalPinToInterrupt(ENCODER_PIN_B), updateEncoder, CHANGE);

  drawMenu();
}

void loop() {
  int newEncoderPosition = encoderPos / 4;
  if (newEncoderPosition != lastEncoderPosition) {
    lastEncoderPosition = newEncoderPosition;
    menuIndex = (newEncoderPosition % menuLength + menuLength) % menuLength;
    drawMenu();
  }

  if (digitalRead(ENCODER_BUTTON_PIN) == LOW) {
    delay(50); // Debounce delay
    if (digitalRead(ENCODER_BUTTON_PIN) == LOW) {
      handleMenuSelection();
      while (digitalRead(ENCODER_BUTTON_PIN) == LOW); // Wait for button release
    }
  }
}

void drawMenu() {
  gfx->fillScreen(BACKGROUND);
  gfx->setCursor(0, 0);
  for (int i = 0; i < menuLength; i++) {
    if (i == menuIndex) {
      gfx->setTextColor(HIGHLIGHT_COLOR);
    } else {
      gfx->setTextColor(TEXT_COLOR);
    }
    gfx->println(menuOptions[i]);
  }
}

void handleMenuSelection() {
  gfx->fillScreen(BACKGROUND);
  gfx->setTextColor(TEXT_COLOR);
  gfx->setCursor(0, 0);
  gfx->println(menuOptions[menuIndex]);
  gfx->println("Opcje dodatkowe:");
  // Dodaj tutaj kod do wyświetlania dodatkowych opcji dla wybranej opcji menu.
}

void updateEncoder() {
  bool data = digitalRead(ENCODER_PIN_A);
  bool clk = digitalRead(ENCODER_PIN_B);
  if(data == clk){
    encoderPos++;
    digitalWrite(25, HIGH);
  }
  else{
    encoderPos--;
    digitalWrite(25, LOW);
  }
}

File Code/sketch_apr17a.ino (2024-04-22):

#include <stdio.h>

#define PIN_CLK 3
#define PIN_DT 2
#define PIN_SW 4

#define PIN_ADC 27

int encoderPos = 0;
int adcValue = 0;

void setup() {
  pinMode(PIN_ADC, INPUT);
  analogReadResolution(12);

  pinMode(PIN_CLK, INPUT);
  pinMode(PIN_DT, INPUT);

  pinMode(25, OUTPUT);
  digitalWrite(25, HIGH);

  attachInterrupt(digitalPinToInterrupt(PIN_CLK), updateEncoder, CHANGE);
  attachInterrupt(digitalPinToInterrupt(PIN_SW), switchPress, CHANGE);

  Serial.begin(9600);
}

void loop() {
  adcValue = analogRead(PIN_ADC);
  Serial.println(3.3/4096 * adcValue);
  delay(500);
}

void updateEncoder() {
  bool data = digitalRead(PIN_DT);
  bool clk = digitalRead(PIN_CLK);
  if(data == clk){
    encoderPos++;
    digitalWrite(25, HIGH);
  }
  else{
    encoderPos--;
    digitalWrite(25, LOW);
  }
}

void switchPress(){
    Serial.println("Sw press");
}

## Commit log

2024-04-16 start project
    [Charger.kicad_pcb, Charger.kicad_sch]
2024-04-18 exel na zakupki
    [zakupy.xlsx]
2024-04-18 schemat balansera
    czesci dodane do exela, dobrane wszystkie rezystory w ltspice do balansera
    [Charger.kicad_sch, zakupy.xlsx]
2024-04-19 sztuczne obciążenie
    [balanser.kicad_sch, ladowarka.kicad_sch, mcu.kicad_sch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]
2024-04-19 powiar rw + zlacze baterii
    koniecznie sprawdzić masy i flagi
    [Charger.kicad_sch, pomiar_pradu.kicad_sch, sztuczne_obciazenie.kicad_sch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]
2024-04-20 update
    zakonczony schemat balansera, sztucznego obciazenia i pomiaru pradu. Przypisane wszystkie footprinty
    [Charger.kicad_sch, balanser.kicad_sch, pomiar_pradu.kicad_sch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]
2024-04-21 Test: enkoder, adc, komunikacja szeregowa
2024-04-21 pcb rev.1 ballancer
    [Charger.kicad_pcb]
2024-04-21 obrocone zlacze balansera
    [Charger.kicad_sch, balanser.kicad_sch]
2024-04-22 Current test
2024-04-22 current test v2
2024-04-22 Znajdowanie adresu i2c i komentarze w testowym
2024-04-23 Unfinished schematic of DC DC converter
    [Przetwornica.kicad_pcb, Przetwornica.kicad_sch]
2024-04-24 next version
    [Przetwornica.kicad_sch, zakupy.xlsx]
2024-04-24 Opisy pinow modulow
    [Charger.kicad_sch]
2024-04-25 dodana ladowarka do glownego projektu
    drobne zmiany w sumie wszedzie pozbyłem sie 3.3v poza sterowaniem z pinów mcu, dopiescilem rezystorki zby bylo jak najmniej wartości rozszerzylem delikatnie zakres pradowy przetwornicy
    [Charger.kicad_sch, balanser.kicad_sch, ladowarka.kicad_sch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]
2024-04-25 Skończone - do przejrzenia
    [Przetwornica.kicad_sch, zakupy.xlsx]
2024-04-25 dodanie sekcji zasilacza
    i dodanie footprintów prawie wszedzie
    [Charger.kicad_sch, ladowarka.kicad_sch, zakupy.xlsx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]
2024-04-25 BŁĄD W PRZETWORNICY
    kondensator za niskie napiecie pracy
    dodanie arkusza zasilacza
    [zakupy.xlsx]
2024-04-26 drobne zmiany
    [ladowarka.kicad_sch, zasilacz.kicad_sch]
2024-04-26 Added Pi Pico model to project
    [mcu.kicad_sch]
2024-04-26 podliczenie dotychczasowych zakupów
    [zakupy.xlsx]
2024-04-26 rozpoczęcie PCB
    zrobiony balanser
    [Charger.kicad_pcb]
2024-04-26 Schematic trace update
    [Charger.kicad_sch, mcu.kicad_sch]
2024-04-26 Semi finished pinning the mcu and added ui pins
    [Charger.kicad_sch, mcu.kicad_sch]
2024-04-27 przegląd
    [Charger.kicad_sch, mcu.kicad_sch]
2024-04-27 Notes after design meeting
    [Charger.kicad_sch, mcu.kicad_sch]
2024-04-27 UPDATE UC
    [Charger.kicad_pcb, Charger.kicad_sch, mcu.kicad_sch]
2024-04-27 pcb up
    [Charger.kicad_pcb, Charger.kicad_sch, ladowarka.kicad_sch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]
2024-04-27 small update
    [Charger.kicad_pcb, Charger.kicad_sch, ladowarka.kicad_sch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]
2024-04-27 pcb poukladane
    usuniete 3 kondensatory
    brak poligonow i odprowadzania ciepla
    [Charger.kicad_pcb, Charger.kicad_sch, ladowarka.kicad_sch]
2024-04-28 PCB V1
    do przerobienia jedynie numery elementów na wartości jedno i drugi w miare poukladane tylko podmienic i posprawdzać
    [Charger.kicad_pcb, Charger.kicad_sch]
2024-04-28 pcb gotowe do sprawdzenia
    [Charger.kicad_pcb]
2024-04-28 Changed SPI connector and MUX pins
    [Charger.kicad_pcb, Charger.kicad_sch, mcu.kicad_sch]
2024-04-29 dodany hall od tylu i opisy
    [Charger.kicad_pcb, pomiar_pradu.kicad_sch]
2024-05-03 Updated buy list with mcu components
    [mcu.kicad_sch, zakupy.xlsx]
2024-05-05 up
    zmienione kilka sciezek, dodane przelotki do masy i rezystor do adc
    [Charger.kicad_pcb, Charger.kicad_sch, mcu.kicad_sch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]
2024-05-06 PCB ostatecznie
    [Charger.kicad_pcb]
2024-05-10 pin definition and declaration
2024-05-10 generated gerbers
    [Charger-B_Cu.gbr, Charger-B_Mask.gbr, Charger-B_Silks.gbr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]
2024-06-01 Updated encoder handling
2024-06-05 btn handling still not working
    [Screen_test.ino]
2024-06-06 poprawki hardware
    [ladowarka.kicad_sch, pomiar_pradu.kicad_sch, zakupy.xlsx]
2024-06-15 fixed main menu infinite scroll
    [Screen_test.ino, test_adc_encoder.ino]
2024-06-16 pliki obudowy
    do poprawy otwory montażowe pcb - na moment robienia jej nie do końca wiedziałem czego chce
    [obudowa_d.stl, obudowa_t.stl]
2024-06-16 aktualizacja schematu
    nie zmieniałem nic na pcb
    [Charger.kicad_sch, pomiar_pradu.kicad_sch, sztuczne_obciazenie.kicad_sch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]
2024-06-17 Fixed selection menu, added parameter setting
    [Screen_test.ino]
2024-06-17 added more adc readouts
2024-06-23 Fixed psuSetV not working correctly
    The rest of sets need to be fixed still
    [Screen_test.ino, test_adc_encoder.ino]
